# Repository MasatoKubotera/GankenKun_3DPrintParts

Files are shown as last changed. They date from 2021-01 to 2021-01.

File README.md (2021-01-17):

# GankenKun_3DPrintParts

---
## Machine
- ### [ANYCUBIC MEGA-S](https://www.amazon.co.jp/ANYCUBIC-3D%E3%83%97%E3%83%AA%E3%83%B3%E3%82%BF%E3%83%BC-%E6%97%A5%E6%9C%AC%E8%AA%9E%E5%8F%96%E6%89%B1%E8%AA%AC%E6%98%8E%E6%9B%B8%E4%BB%98%E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)

  

  - #### Introduction date
    - 2020/11/19
---
## Software
- ### Create 3D model
  - #### [AUTODESK INVENTOR](https://www.autodesk.co.jp/products/inventor)

- ### 3D Printing
  - #### [Ultimaker Cura](https://ultimaker.com/ja/software/ultimaker-cura)

- ### STL data editing
  - #### [blender](https://www.blender.org/)
  
---
## Folder / File
- ### [PLA](/PLA)
  - #### [README](/PLA/README.md)

- ### [TPU](/TPU)
  - #### [README](/TPU/README.md)

- ### [Temp_Calibration_Tower](/Temp_Calibration_Tower)
  - #### [README](/Temp_Calibration_Tower/README.md)

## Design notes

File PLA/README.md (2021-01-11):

# PLA
---
## Table of contents
-   [Filament](https://github.com/MasatoKubotera/GankenKun_3DPrintParts/tree/master/PLA#filament)
-   [Basic Parameteres](https://github.com/MasatoKubotera/GankenKun_3DPrintParts/tree/master/PLA#basic-parameteres)
-   Parts
    -   [Antenna](https://github.com/MasatoKubotera/GankenKun_3DPrintParts/tree/master/PLA#antenna)
    -   [New_Accelite_Controller_Cover](https://github.com/MasatoKubotera/GankenKun_3DPrintParts/tree/master/PLA#new_accelite_controller_cover)
    -   [SwitchCov](https://github.com/MasatoKubotera/GankenKun_3DPrintParts/tree/master/PLA#switchcov)
    -   [カメラ_外装](https://github.com/MasatoKubotera/GankenKun_3DPrintParts/tree/master/PLA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)
    -   [コックピット](https://github.com/MasatoKubotera/GankenKun_3DPrintParts/tree/master/PLA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)
    -   [腕先](https://github.com/MasatoKubotera/GankenKun_3DPrintParts/tree/master/PLA#%E8%85%95%E5%85%88)

---
## Filament
-   [ANYCUBIC PLA](https://www.amazon.co.jp/ANYCUBIC-3D%E3%83%97%E3%83%AA%E3%83%B3%E3%82%BF%E3%83%BC%E7%94%A8-%E3%83%95%E3%82%A3%E3%83%A9%E3%83%A1%E3%83%B3%E3%83%88-%E7%92%B0%E5%A2%83%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)

    

---
## Basic Parameteres

|Name|Parameter|
|---|---|
|**Infill Density [%]**<br>インフィル密度|20|
|**Infill Pattern**<br>初期レイヤー高さ|Gyroid|
|**Printing Temperature [℃]**<br>印刷温度|200|
|**Bulid Plate Temperature [℃]**<br>ビルドプレート温度|60|
|**Print Speed [mm/s]**<br>印刷速度|60|
|**Initial Layer Speed [mm/s]**<br>初期レイヤー印刷速度|5|
|**Enable Retraction**<br>引き戻し有効|available|
|**Enable Print Cooling**<br>印刷中の冷却を有効にする|available|
|**Build Plate Adhesion Type**<br>ビルドプレート接着タイプ|Skirt|

---
## Antenna

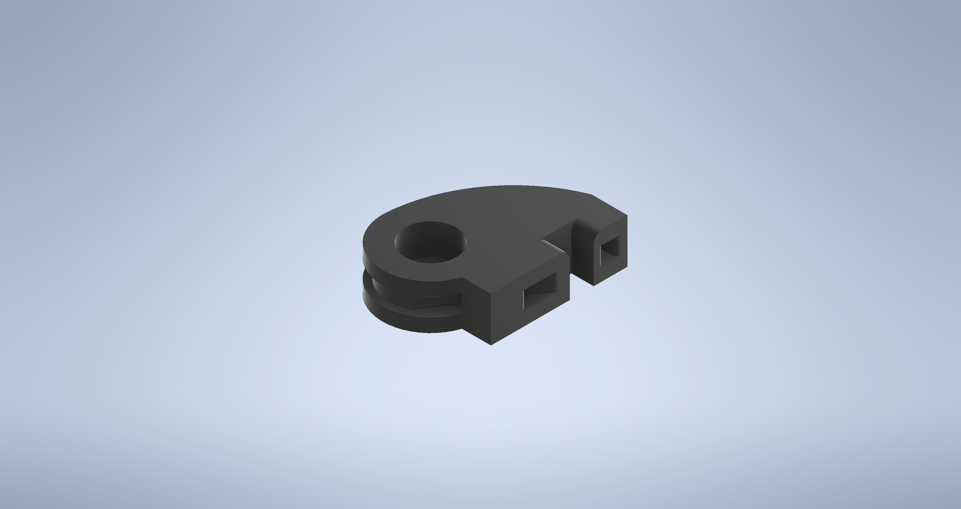
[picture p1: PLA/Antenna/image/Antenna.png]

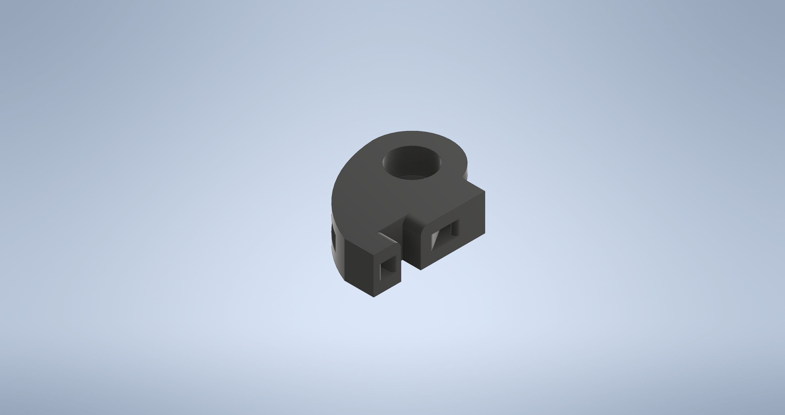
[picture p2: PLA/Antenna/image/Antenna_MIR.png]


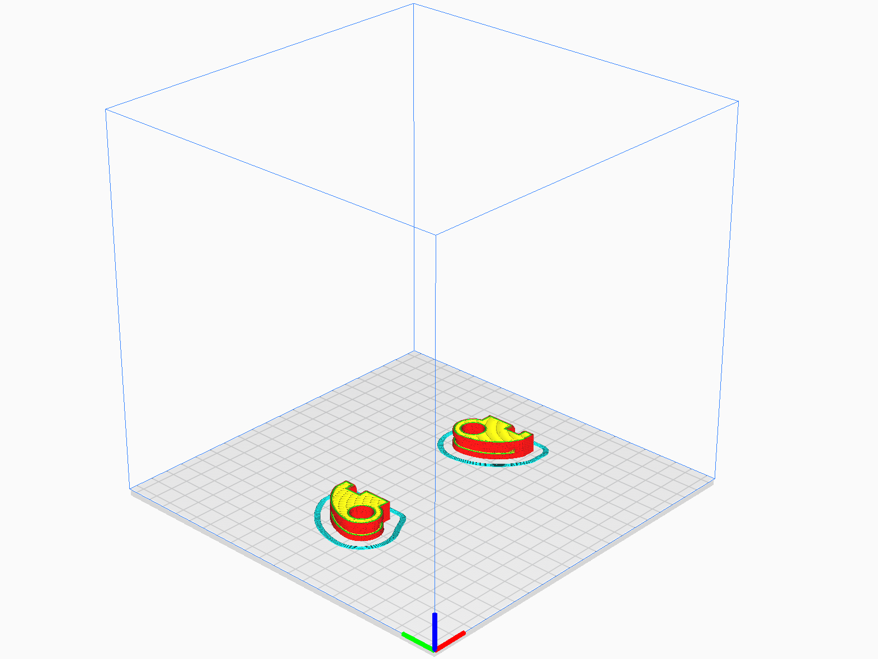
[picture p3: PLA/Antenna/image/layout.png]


-   ### Files

    -   #### CAD  
        -   [Antenna.ipt](https://github.com/citbrains/OpenPlatform/blob/a4b5907f3c764cb437537e5cbbeef6c4c5cdda09/mechanism/OpenPlatform_ver3_0/%E4%B8%8A%E5%8D%8A%E8%BA%AB/%E3%82%B3%E3%83%83%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)

            `OpenPlatform/mechanism/OpenPlatform_ver3_0/上半身/コックピット/コックピット_2/Antenna.ipt`
            
        -   [Antenna_MIR.ipt](https://github.com/citbrains/OpenPlatform/blob/a4b5907f3c764cb437537e5cbbeef6c4c5cdda09/mechanism/OpenPlatform_ver3_0/%E4%B8%8A%E5%8D%8A%E8%BA%AB/%E3%82%B3%E3%83%83%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)

            `OpenPlatform/mechanism/OpenPlatform_ver3_0/上半身/コックピット/コックピット_2/Antenna_MIR.ipt`

    -   #### STL
        -   [Antenna.stl](Antenna.stl)
        -   [Antenna_MIR.stl](Antenna_MIR.stl)

    -   #### Gcode
        -   [Antennas.gcode](Antennas.gcode)

    -   #### Profile
        -   [Antenna.curaprofile](Antenna.curaprofile)

-   ### Characteristical parameteres
    |Parameter Name|Parameter|
    |---|---|
    |**Layer Hight [mm]**<br>レイヤー高さ|0.2|
    |**Generate Support**<br>サポート開始|N/A|

-   ### Quantity
    -   1 pc of each

-   ### Estimated print time
    -   1 h 11 m

-   ### Additional processing
    -   N/A

-   ### Works cited
    -   N/A

---
## New_Accelite_Controller_Cover

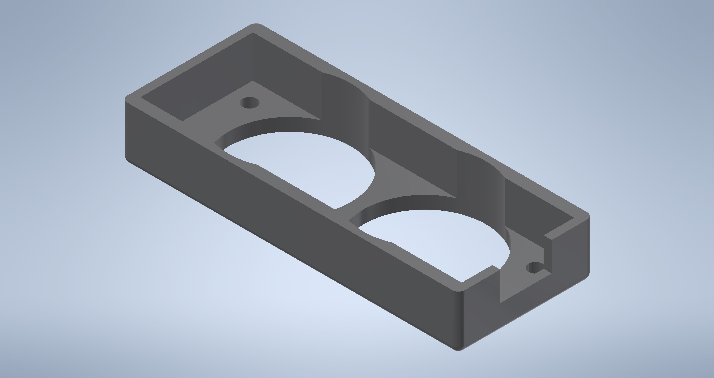
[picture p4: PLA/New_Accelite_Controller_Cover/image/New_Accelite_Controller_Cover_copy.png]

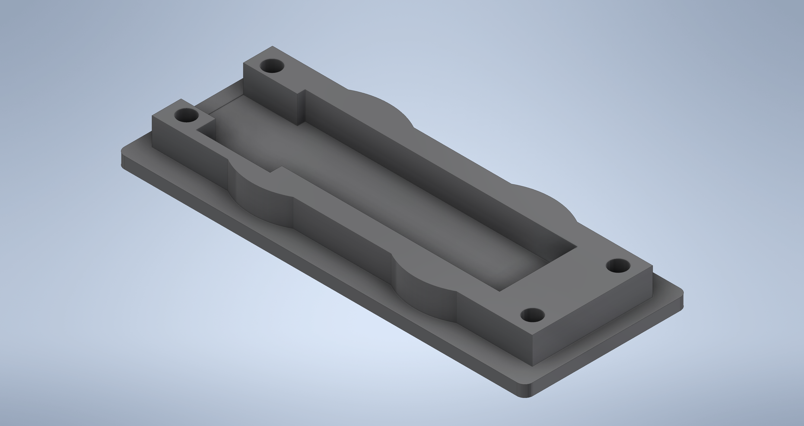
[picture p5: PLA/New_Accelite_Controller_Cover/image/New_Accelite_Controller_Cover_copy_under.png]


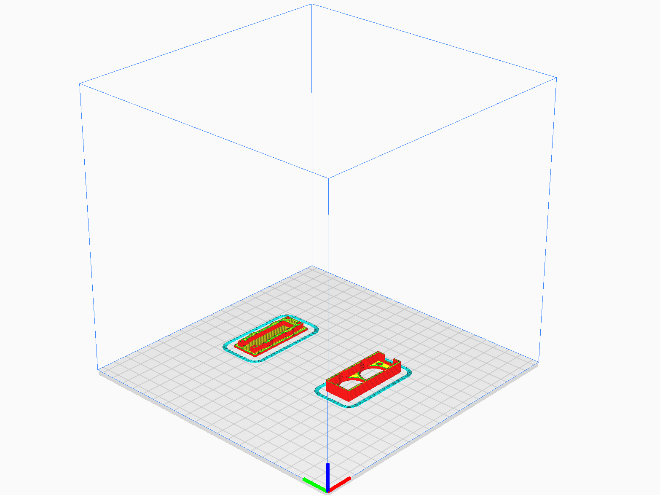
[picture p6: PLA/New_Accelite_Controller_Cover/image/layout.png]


-   ### Files

    -   #### CAD  
        -   [New_Accelite_Controller_Cover_copy.ipt](https://github.com/citbrains/OpenPlatform/blob/a4b5907f3c764cb437537e5cbbeef6c4c5cdda09/mechanism/OpenPlatform_ver3_0/%E4%B8%8A%E5%8D%8A%E8%BA%AB/%E3%82%B3%E3%83%83%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)

            `OpenPlatform/mechanism/OpenPlatform_ver3_0/上半身/コックピット/コックピット_2/New_Accelite_Controller_Cover_copy.ipt`

        - [New_Accelite_Controller_Cover_copy_under.ipt](https://github.com/citbrains/OpenPlatform/blob/a4b5907f3c764cb437537e5cbbeef6c4c5cdda09/mechanism/OpenPlatform_ver3_0/%E4%B8%8A%E5%8D%8A%E8%BA%AB/%E3%82%B3%E3%83%83%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)

            `OpenPlatform/mechanism/OpenPlatform_ver3_0/上半身/コックピット/コックピット_2/New_Accelite_Controller_Cover_copy_under.ipt`

    -   #### STL
        - [New_Accelite_Controller_Cover_copy.stl](New_Accelite_Controller_Cover/New_Accelite_Controller_Cover_copy.stl)

        - [New_Accelite_Controller_Cover_copy_under.stl](New_Accelite_Controller_Cover/New_Accelite_Controller_Cover_copy_under.stl)

    -   #### Gcode
        - [Controller_Cover.gcode](New_Accelite_Controller_Cover/Controller_Cover.gcode)

    -   #### Profile
        - [Controller_Cover.curaprofile](New_Accelite_Controller_Cover/Controller_Cover.curaprofile)

-   ### Characteristical parameteres
    |Parameter Name|Parameter|
    |---|---|
    |**Layer Hight [mm]**<br>レイヤー高さ|0.2|
    |**Generate Support**<br>サポート開始|N/A|

-   ### Quantity
    -   1 pc of each

-   ### Estimated print time
    -   48 m

-   ### Additional processing
    -   N/A

-   ### Works cited
    -   N/A
    
---
## SwitchCov

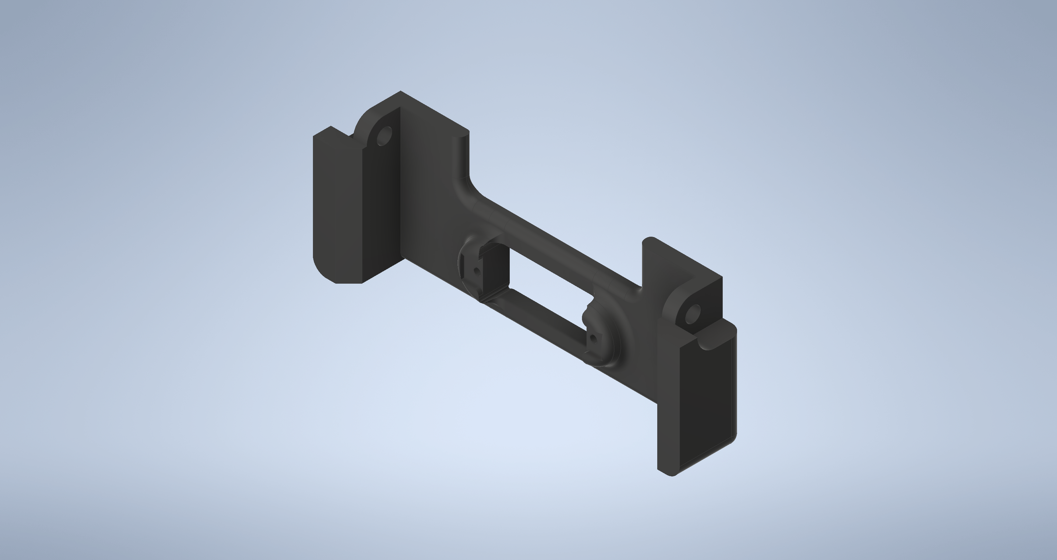
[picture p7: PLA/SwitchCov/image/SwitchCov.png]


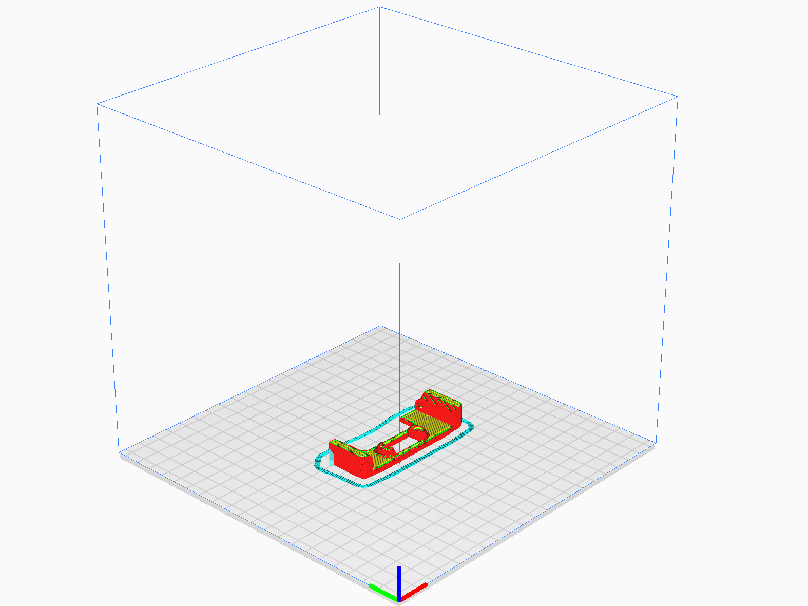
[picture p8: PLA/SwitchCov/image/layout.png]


-   ### Files

    -   #### CAD
        
        Improvement version Branch : [Fix_SwitchCov](https://github.com/citbrains/OpenPlatform/tree/Fix_SwitchCov)

        STL version : commit [1c000b001d7586965ef5ba650b1c151932267094](https://github.com/citbrains/OpenPlatform/tree/1c000b001d7586965ef5ba650b1c151932267094)        

        - [SwitchCov.ipt]()

          `OpenPlatform/mechanism/OpenPlatform_ver3_0/上半身/コックピット/コックピット_2/SwitchCov.ipt`

    -   #### STL
        - [SwitchCov.stl](SwitchCov.stl)

    -   #### Gcode
        - [SwitchCov.gcode](SwitchCov.gcode)

    -   #### Profile
        - [SwitchCov.curaprofile](SwitchCov.curaprofile)

-   ### Characteristical parameteres
    |Parameter Name|Parameter|
    |---|---|
    |**Layer Hight [mm]**<br>レイヤー高さ|0.2|
    |**Generate Support**<br>サポート開始|available|

-   ### Quantity
    -   1 pc

-   ### Estimated print time
    -   1 h 3 m

-   ### Additional processing
    -   ネジ切り M2 * 2

-   ### Works cited
    -   N/A
    
---
## カメラ_外装

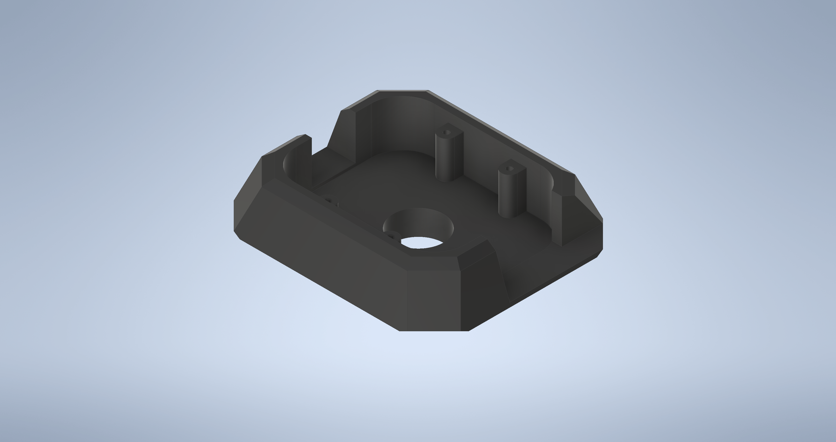
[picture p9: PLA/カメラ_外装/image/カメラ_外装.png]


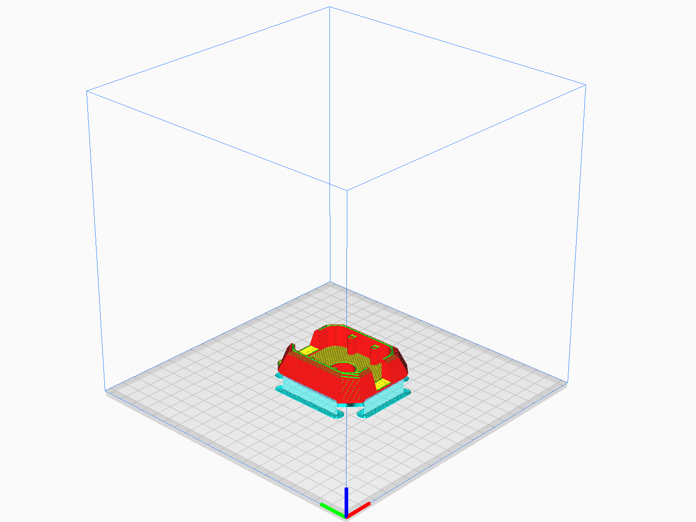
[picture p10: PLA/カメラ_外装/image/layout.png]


-   ### Files

    -   #### CAD

        - [カメラ_外装.ipt](https://github.com/citbrains/OpenPlatform/blob/a4b5907f3c764cb437537e5cbbeef6c4c5cdda09/mechanism/OpenPlatform_ver3_0/%E4%B8%8A%E5%8D%8A%E8%BA%AB/%E9%A0%AD/%E3%82%AB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)

          `OpenPlatform/mechanism/OpenPlatform_ver3_0/上半身/頭/カメラ_外装.ipt
`

    -   #### STL
        - [カメラ_外装.stl](カメラ_外装/カメラ_外装.stl)

    -   #### Gcode
        - [Camera.gcode](カメラ_外装/Camera.gcode)

    -   #### Profile
        - [Camera.curaprofile](カメラ_外装/Camera.curaprofile)

-   ### Characteristical parameteres
    |Parameter Name|Parameter|
    |---|---|
    |**Layer Hight [mm]**<br>レイヤー高さ|0.2|
    |**Generate Support**<br>サポート開始|available|

-   ### Quantity
    -   1 pc

-   ### Estimated print time
    -   2 h 52 m

-   ### Additional processing
    -   ネジ切り M2 * 4

-   ### Works cited
    -   N/A
    
---
## コックピット

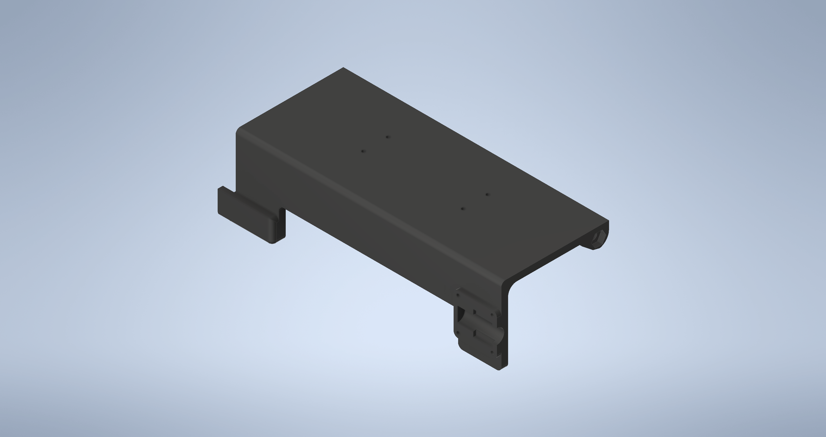
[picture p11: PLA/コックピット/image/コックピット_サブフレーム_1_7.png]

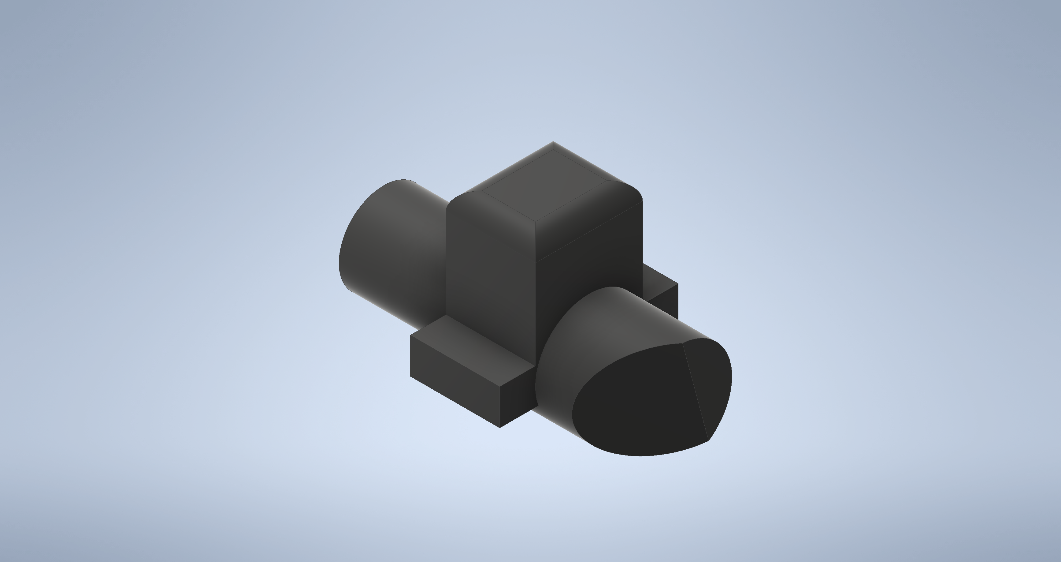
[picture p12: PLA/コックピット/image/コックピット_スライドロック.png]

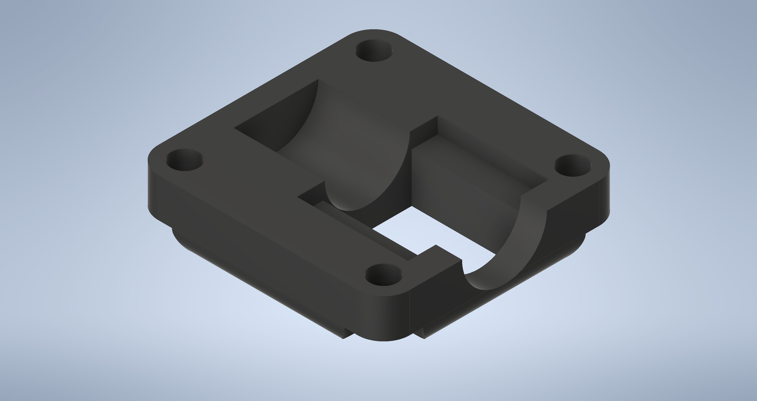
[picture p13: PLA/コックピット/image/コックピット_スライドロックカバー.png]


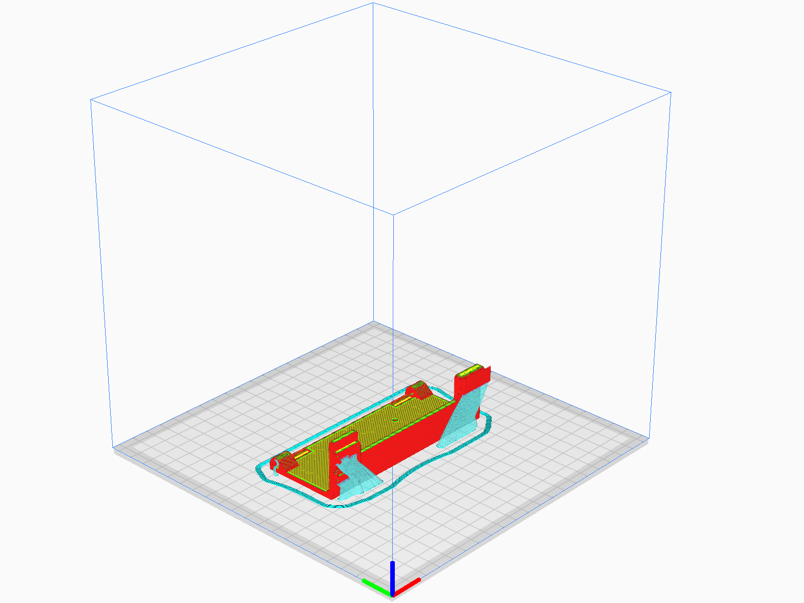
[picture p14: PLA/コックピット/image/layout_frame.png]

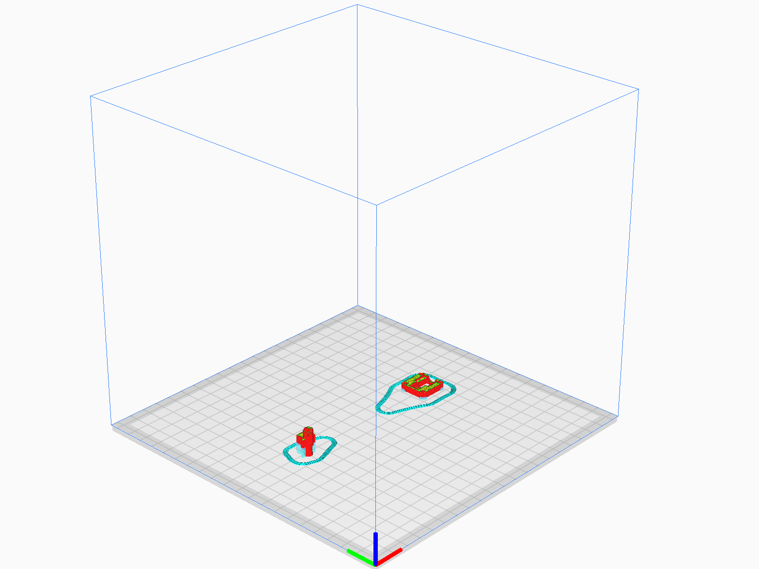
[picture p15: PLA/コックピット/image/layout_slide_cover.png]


-   ### Files

    -   #### CAD

        Improvement version Branch : [New_BatteryBox](https://github.com/citbrains/OpenPlatform/tree/New_BatteryBox)

        STL version : commit [43e9e1346e4216fdac78b60479cbb7ee6bb19e6d](https://github.com/citbrains/OpenPlatform/commit/43e9e1346e4216fdac78b60479cbb7ee6bb19e6d)
        
        - [コックピット_サブフレーム_1_7.ipt](https://github.com/citbrains/OpenPlatform/blob/43e9e1346e4216fdac78b60479cbb7ee6bb19e6d/mechanism/OpenPlatform_ver3_0/%E4%B8%8A%E5%8D%8A%E8%BA%AB/%E3%82%B3%E3%83%83%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)

          `OpenPlatform/mechanism/OpenPlatform_ver3_0/上半身/コックピット/コックピット_2/コックピット_サブフレーム_1_7.ipt`

        - [コックピット_スライドロック.ipt](https://github.com/citbrains/OpenPlatform/blob/43e9e1346e4216fdac78b60479cbb7ee6bb19e6d/mechanism/OpenPlatform_ver3_0/%E4%B8%8A%E5%8D%8A%E8%BA%AB/%E3%82%B3%E3%83%83%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)

          `OpenPlatform/mechanism/OpenPlatform_ver3_0/上半身/コックピット/コックピット_2/コックピット_スライドロック.ipt`

        - [コックピット_スライドロックカバー.ipt](https://github.com/citbrains/OpenPlatform/blob/43e9e1346e4216fdac78b60479cbb7ee6bb19e6d/mechanism/OpenPlatform_ver3_0/%E4%B8%8A%E5%8D%8A%E8%BA%AB/%E3%82%B3%E3%83%83%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)

          `OpenPlatform/mechanism/OpenPlatform_ver3_0/上半身/コックピット/コックピット_2/コックピット_スライドロックカバー.ipt`

    -   #### STL
        - [コックピット_サブフレーム_1_7.stl](コックピット/コックピット_サブフレーム_1_7.stl)

        - [コックピット_スライドロック.stl](コックピット/コックピット_スライドロック.stl)

        - [コックピット_スライドロックカバー.stl](コックピット/コックピット_スライドロックカバー.stl)

    -   #### Gcode
        - [Frame.gcode](コックピット/Frame.gcode)

        - [Slide_Cover.gcode](コックピット/Slide_Cover.gcode)

    -   #### Profile

        - [Frame.curaprofile](コックピット/Frame.curaprofile)

        - [Slide_Cover.curaprofile](コックピット/Slide_Cover.curaprofile)

-   ### Characteristical parameteres
    |Parameter Name|Parameter|
    |---|---|
    |**Layer Hight [mm]**<br>レイヤー高さ|0.2|
    |**Generate Support**<br>サポート開始|available|

    - Support Structure (サポート構造)
      - コックピット_サブフレーム_1_7 : Tree
      - コックピット_スライドロック & コックピット_スライドロックカバー : Normal

-   ### Quantity
    -   1 pc of each

-   ### Estimated print time
    -   コックピット_サブフレーム_1_7
        -   3 h 33 m

    -   コックピット_スライドロック & コックピット_スライドロックカバー
        -   34 m

-   ### Additional processing
    -   コックピット_サブフレーム_1_7
        -   ネジ切り M2 * 4

-   ### Works cited
    -   N/A
    
---
## 腕先

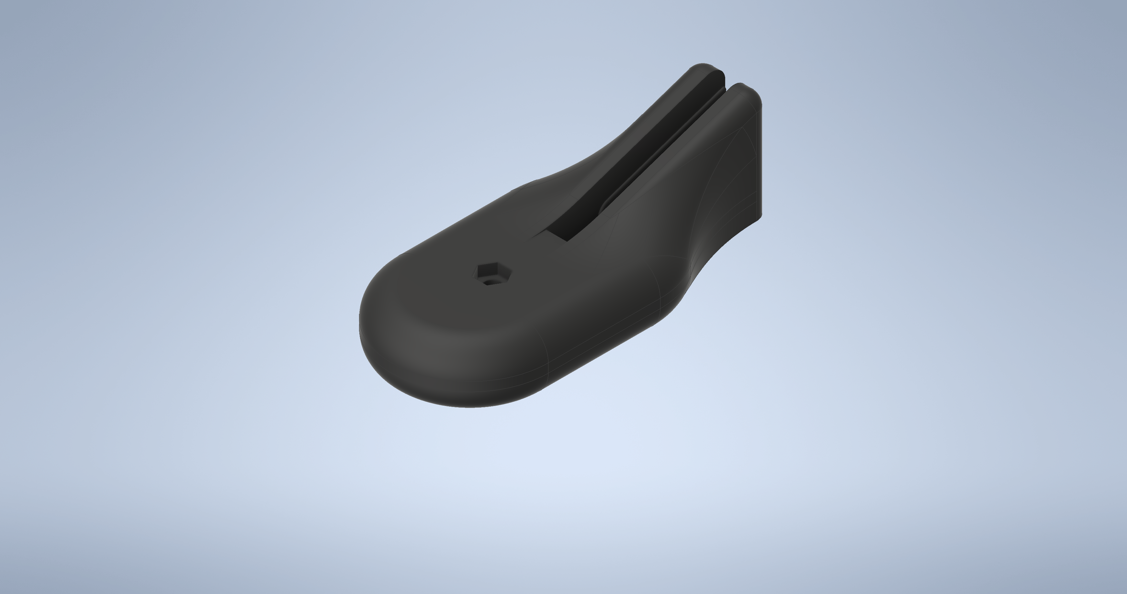
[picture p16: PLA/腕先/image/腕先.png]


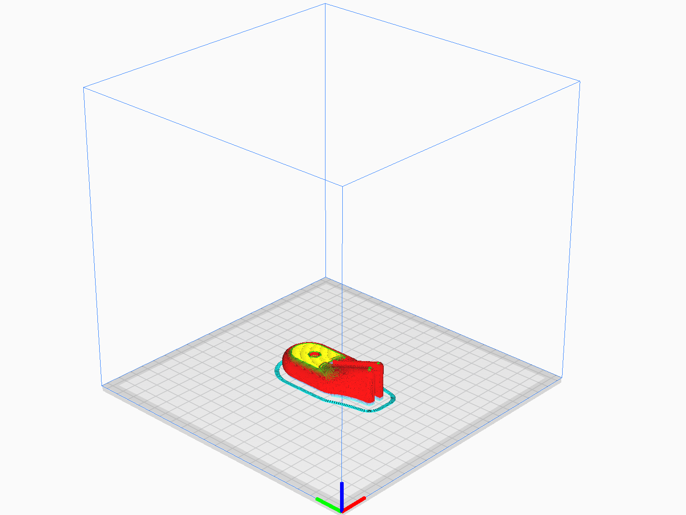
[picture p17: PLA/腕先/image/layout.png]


-   ### Files

    -   #### CAD  
        - [腕先.ipt](https://github.com/citbrains/OpenPlatform/blob/a4b5907f3c764cb437537e5cbbeef6c4c5cdda09/mechanism/OpenPlatform_ver3_0/%E4%B8%8A%E5%8D%8A%E8%BA%AB/%E8%85%95/%E8%85%95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)

          `OpenPlatform/mechanism/OpenPlatform_ver3_0/上半身/腕/腕先.ipt`

    -   #### STL
        - [腕先.stl](腕先/腕先.stl)

    -   #### Gcode
        - [Hand.gcode](腕先/Hand.gcode)

    -   #### Profile
        - [Hand.curaprofile](腕先/Hand.curaprofile)

-   ### Characteristical parameteres
    |Parameter Name|Parameter|
    |---|---|
    |**Layer Hight [mm]**<br>レイヤー高さ|0.2|
    |**Generate Support**<br>サポート開始|available|

-   ### Quantity
    -   2 pcs

-   ### Estimated print time
    -   1 h 36 m / 1 pc

-   ### Additional processing
    -   N/A

-   ### Works cited
    -   N/A

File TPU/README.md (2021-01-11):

# TPU
---
## Table of contents
-   [Filament](https://github.com/MasatoKubotera/GankenKun_3DPrintParts/tree/master/TPU#filament)
-   [Basic Parameteres](https://github.com/MasatoKubotera/GankenKun_3DPrintParts/tree/master/TPU#basic-parameteres)
-   Parts
    -   [CameraCable_Assist](https://github.com/MasatoKubotera/GankenKun_3DPrintParts/tree/master/TPU#cameracable_assist)
    -   [FreundBumper_Stand](https://github.com/MasatoKubotera/GankenKun_3DPrintParts/tree/master/TPU#freundbumper_stand)
    -   [FrontBumper_main](https://github.com/MasatoKubotera/GankenKun_3DPrintParts/tree/master/TPU#frontbumper_main)
    -   [RearBumper_Lower](https://github.com/MasatoKubotera/GankenKun_3DPrintParts/tree/master/TPU#rearbumper_lower)
    -   [SideBumper](https://github.com/MasatoKubotera/GankenKun_3DPrintParts/tree/master/TPU#sidebumper)

---
## Filament
-   [Pxmalion Flexible TPU](https://www.amazon.co.jp/dp/B074W3Y44S)

    

---
## Basic Parameteres

|Name|Parameter|
|---|---|
|**Initial Layer Hight [mm]**<br>初期レイヤー高さ|0.3|
|**Initial Layer Line Width [%]**<br>|125|
|**Printing Temperature [℃]**<br>印刷温度|190|
|**Bulid Plate Temperature [℃]**<br>ビルドプレート温度|0 ~ 60|
|**Print Speed [mm/s]**<br>印刷速度|30|
|**Initial Layer Speed [mm/s]**<br>初期レイヤー印刷速度|15|
|**Enable Retraction**<br>引き戻し有効|N/A|
|**Enable Print Cooling**<br>印刷中の冷却を有効にする|available|
|**Generate Support**<br>サポート開始|N/A|

---
## CameraCable_Assist

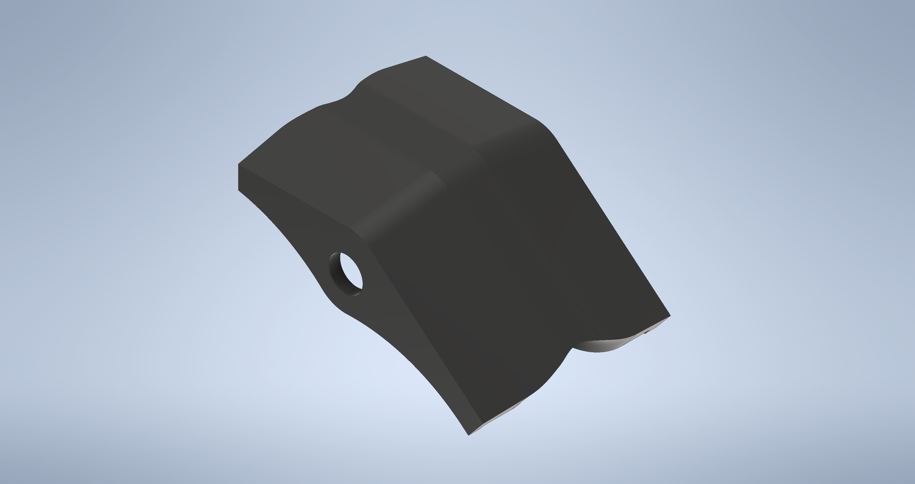
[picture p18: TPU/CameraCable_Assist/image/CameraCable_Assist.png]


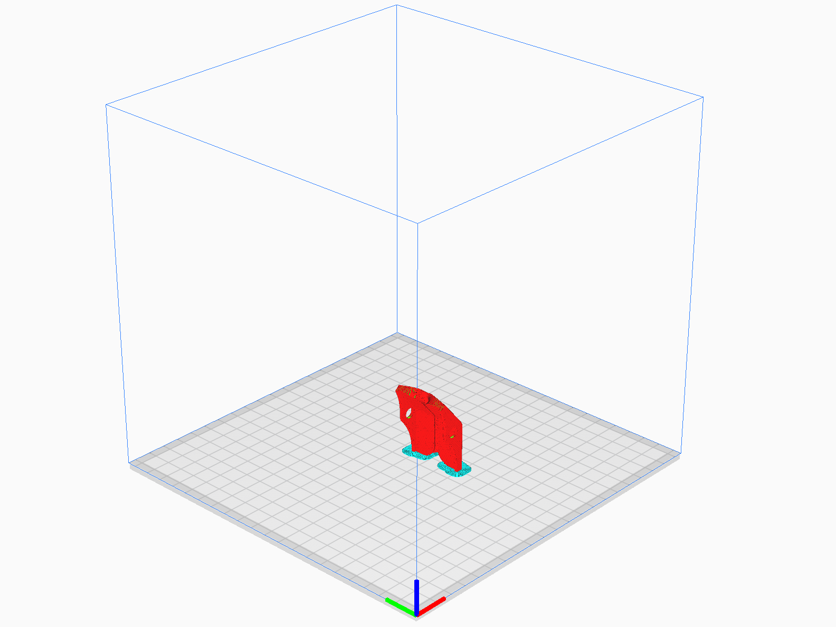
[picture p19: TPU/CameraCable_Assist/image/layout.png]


-   ### Files

    -   #### CAD  
        -   [CameraCable_Assist.ipt](https://github.com/citbrains/OpenPlatform/tree/a4b5907f3c764cb437537e5cbbeef6c4c5cdda09/mechanism/OpenPlatform_ver3_0/%E4%B8%8A%E5%8D%8A%E8%BA%AB/%E9%A0%AD/CameraCab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)

            `OpenPlatform/mechanism/OpenPlatform_ver3_0/上半身/頭/CameraCable_Assist.ipt`

    -   #### STL
        -   [CameraCable_Assist.stl](CameraCable_Assist/CameraCable_Assist.stl)

    -   #### Gcode
        -   [Cable_Assist.gcode](CameraCable_Assist/Cable_Assist.gcode)

    -   #### Profile
        -   [Cable_Assist.curaprofile](CameraCable_Assist/Cable_Assist.curaprofile)

-   ### Characteristical parameteres
    |Parameter Name|Parameter|
    |---|---|
    |**Infill Density [%]**<br>インフィル密度|100|
    |**Layer Hight [mm]**<br>レイヤー高さ|0.2|
    |**Bulid Plate Temperature [℃]**<br>ビルドプレート温度|0|
    |**Build Plate Adhesion Type**<br>ビルドプレート接着タイプ|Brim|

-   ### Quantity
    -   1 pc

-   ### Estimated print time
    -   1 h 36 m

-   ### Additional processing
    -   N/A

-   ### Works cited
    -   N/A

---
## FreundBumper_Stand

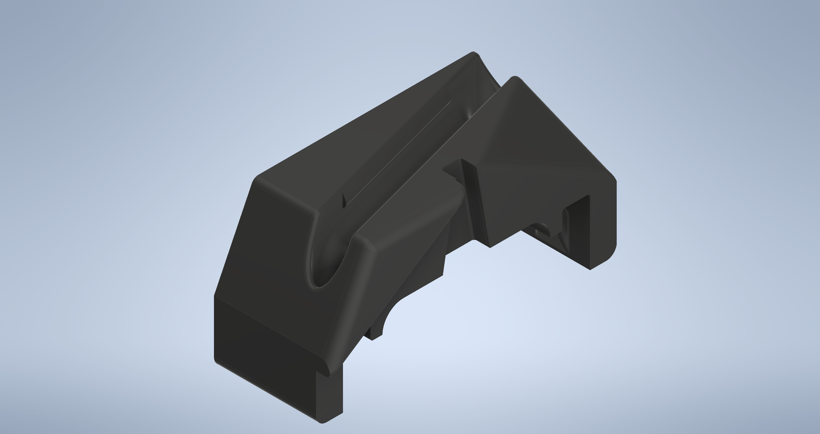
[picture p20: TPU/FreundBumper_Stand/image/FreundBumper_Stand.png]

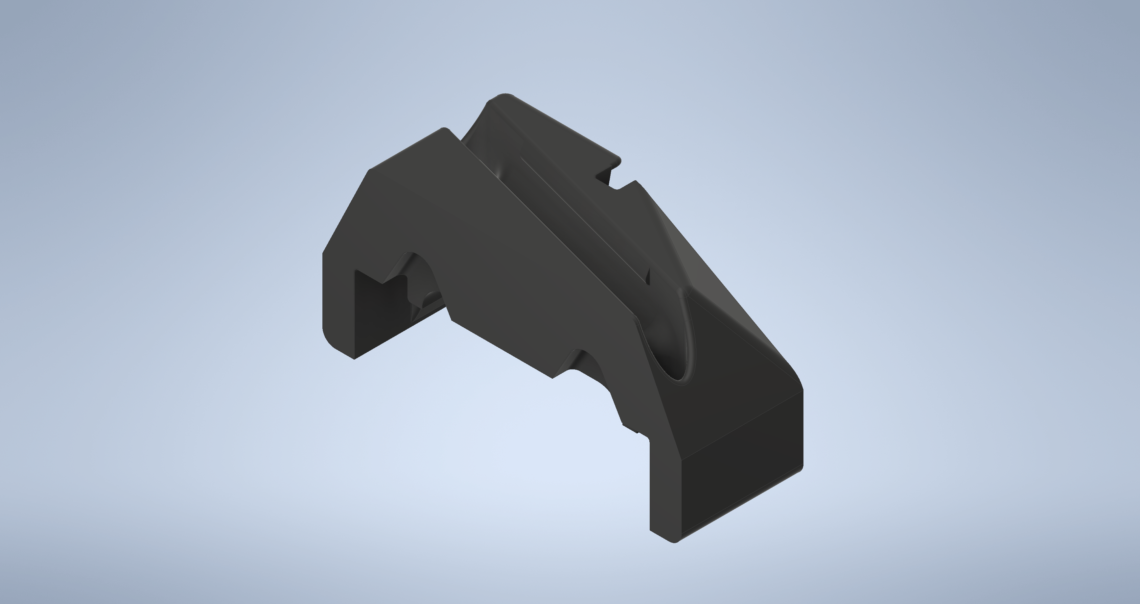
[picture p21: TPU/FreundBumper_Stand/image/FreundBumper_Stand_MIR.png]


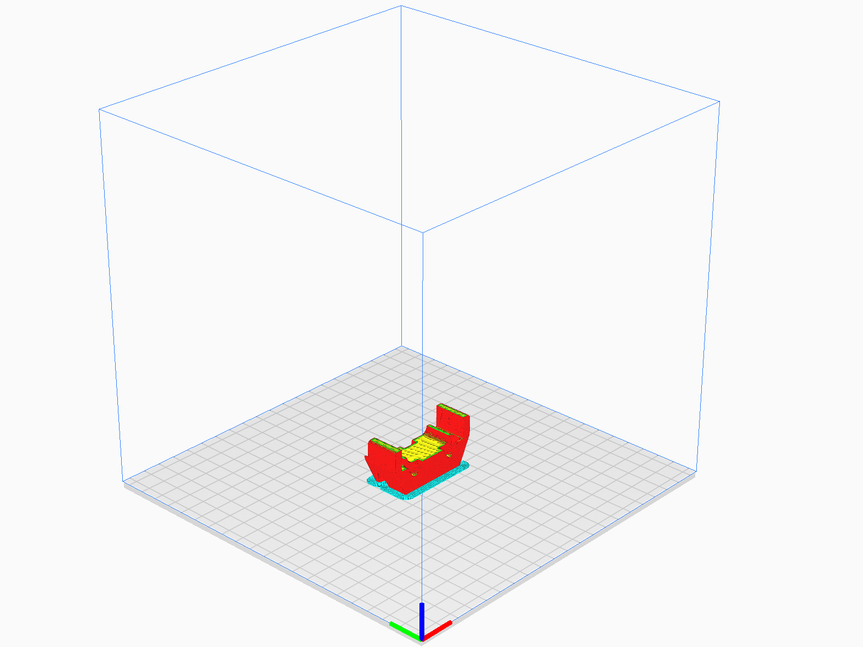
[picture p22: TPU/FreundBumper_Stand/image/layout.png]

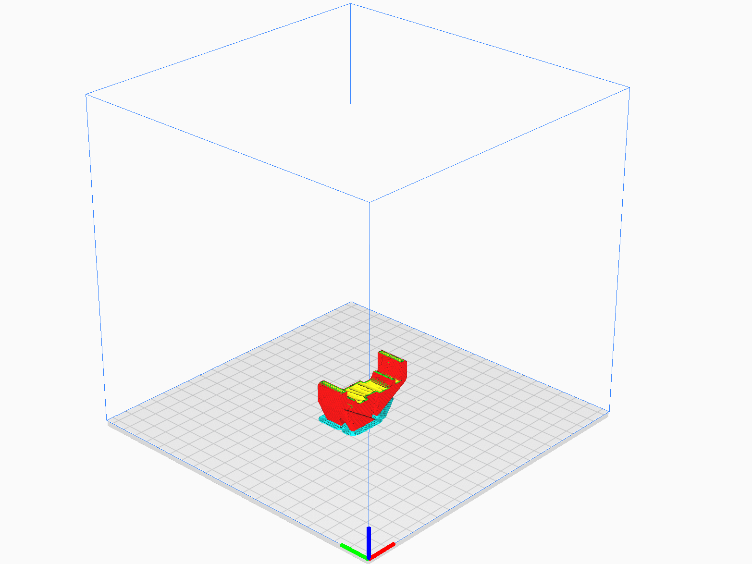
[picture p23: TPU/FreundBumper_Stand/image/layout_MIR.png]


-   ### Files

    -   #### CAD  
        -   [FreundBumper_Stand.ipt](https://github.com/citbrains/OpenPlatform/tree/a4b5907f3c764cb437537e5cbbeef6c4c5cdda09/mechanism/OpenPlatform_ver3_0/%E4%B8%8A%E5%8D%8A%E8%BA%AB/%E8%83%B4%E4%BD%93/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)

            `OpenPlatform/mechanism/OpenPlatform_ver3_0/上半身/胴体/FreundBumper_Stand.ipt`

        -   [FreundBumper_Stand_MIR.ipt](https://github.com/citbrains/OpenPlatform/tree/a4b5907f3c764cb437537e5cbbeef6c4c5cdda09/mechanism/OpenPlatform_ver3_0/%E4%B8%8A%E5%8D%8A%E8%BA%AB/%E8%83%B4%E4%BD%93/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)

            `OpenPlatform/mechanism/OpenPlatform_ver3_0/上半身/胴体/FreundBumper_Stand_MIR.ipt`

    -   #### STL
        -   [FreundBumper_Stand.stl](FreundBumper_Stand/FreundBumper_Stand.stl)
        -   [FreundBumper_Stand_MIR.stl](FreundBumper_Stand/FreundBumper_Stand_MIR.stl)

    -   #### Gcode
        -   [Bumper_Stand.gcode](FreundBumper_Stand/Bumper_Stand.gcode)
        -   [Bumper_Stand_MIR.gcode](FreundBumper_Stand/Bumper_Stand_MIR.gcode)

    -   #### Profile
        -   [Bumper_Stand.curaprofile](FreundBumper_Stand/Bumper_Stand.curaprofile)

-   ### Characteristical parameteres
    |Parameter Name|Parameter|
    |---|---|
    |**Infill Density [%]**<br>インフィル密度|100|
    |**Layer Hight [mm]**<br>レイヤー高さ|0.2|
    |**Bulid Plate Temperature [℃]**<br>ビルドプレート温度|60|
    |**Build Plate Adhesion Type**<br>ビルドプレート接着タイプ|Brim|

-   ### Quantity
    -   1 pc of each

-   ### Estimated print time
    -   3 h 22 m of each

-   ### Additional processing
    -   N/A

-   ### Works cited
    -   [issue](https://github.com/citbrains/citbrains_humanoid/issues/999#issuecomment-499572870)

---
## FrontBumper_main

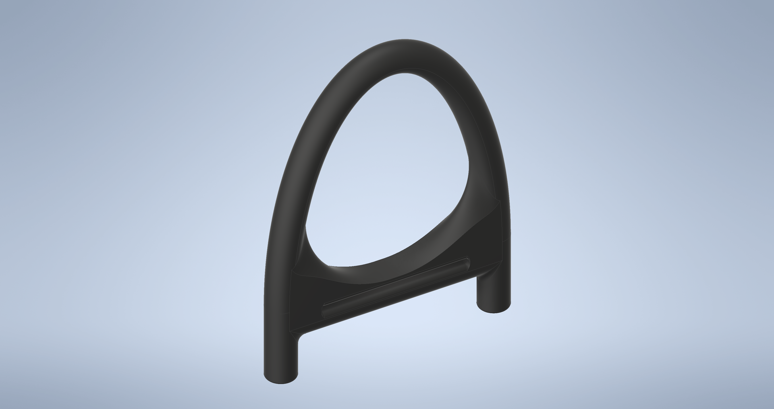
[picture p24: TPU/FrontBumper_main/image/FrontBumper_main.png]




-   ### Files

    -   #### CAD  
        -   [FrontBumper_main.ipt](https://github.com/citbrains/OpenPlatform/blob/a4b5907f3c764cb437537e5cbbeef6c4c5cdda09/mechanism/OpenPlatform_ver3_0/%E4%B8%8A%E5%8D%8A%E8%BA%AB/%E8%83%B4%E4%BD%93/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)

            `OpenPlatform/mechanism/OpenPlatform_ver3_0/上半身/胴体/FrontBumper_main.ipt`

    -   #### STL
        -   [FrontBumpe_mainr.stl](FrontBumpe_mainr/FrontBumpe_mainr.stl)

    -   #### Gcode
        -   [FrontBumper_main.gcode](FrontBumpe_mainr/FrontBumper_main.gcode)

    -   #### Profile
        -   [FrontBumper.curaprofeil](FrontBumpe_mainr/FrontBumper.curaprofeil)

-   ### Characteristical parameteres
    |Parameter Name|Parameter|
    |---|---|
    |**Infill Density [%]**<br>インフィル密度|100|
    |**Layer Hight [mm]**<br>レイヤー高さ|0.1|
    |**Bulid Plate Temperature [℃]**<br>ビルドプレート温度|60|
    |**Build Plate Adhesion Type**<br>ビルドプレート接着タイプ|Skirt|

-   ### Quantity
    -   2 pcs

-   ### Estimated print time
    -   2 h 46 m / 1 pc

-   ### Additional processing
    -   N/A

-   ### Works cited
    -   [issue](https://github.com/citbrains/citbrains_humanoid/issues/999#issuecomment-499572870)

---
## RearBumper_Lower







-   ### Files

    -   #### CAD  
        -   [RearBumper_Lower.ipt](https://github.com/citbrains/OpenPlatform/blob/a4b5907f3c764cb437537e5cbbeef6c4c5cdda09/mechanism/OpenPlatform_ver3_0/%E4%B8%8A%E5%8D%8A%E8%BA%AB/%E8%83%B4%E4%BD%93/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)

            `OpenPlatform/mechanism/OpenPlatform_ver3_0/上半身/胴体/RearBumper_Lower.ipt`

        -   [RearBumper_Lower_MIR.ipt](https://github.com/citbrains/OpenPlatform/blob/a4b5907f3c764cb437537e5cbbeef6c4c5cdda09/mechanism/OpenPlatform_ver3_0/%E4%B8%8A%E5%8D%8A%E8%BA%AB/%E8%83%B4%E4%BD%93/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)
            
            `OpenPlatform/mechanism/OpenPlatform_ver3_0/上半身/胴体/RearBumper_Lower_MIR.ipt`

    -   #### STL
        -   [RearBumper_Lower.stl](RearBumper_Lower/RearBumper_Lower.stl)
        -   [RearBumper_Lower_MIR.stl](RearBumper_Lower/RearBumper_Lower_MIR.stl)

    -   #### Gcode
        -   [Bumper_Lower.gcode](RearBumper_Lower/Bumper_Lower.gcode)
        -   [Bumper_Lower_MIR.gcode](RearBumper_Lower/Bumper_Lower/RearBumper_Lower_MIR.gcode)

    -   #### Profile
        -   [RearBumpere_Lower.curaprofile](RearBumper_Lower/RearBumpere_Lower.curaprofile)

-   ### Characteristical parameteres
    |Parameter Name|Parameter|
    |---|---|
    |**Infill Density [%]**<br>インフィル密度|100|
    |**Layer Hight [mm]**<br>レイヤー高さ|0.2|
    |**Bulid Plate Temperature [℃]**<br>ビルドプレート温度|60|
    |**Build Plate Adhesion Type**<br>ビルドプレート接着タイプ|Skirt|

-   ### Quantity
    -   1 pc of each

-   ### Estimated print time
    -   2 h 51 m of each

-   ### Additional processing
    -   N/A

-   ### Works cited
    -   [issue](https://github.com/citbrains/citbrains_humanoid/issues/1197)

---
## SideBumper





-   ### Files

    -   #### CAD  
        -   [SideBumper.ipt](https://github.com/citbrains/OpenPlatform/blob/a4b5907f3c764cb437537e5cbbeef6c4c5cdda09/mechanism/OpenPlatform_ver3_0/%E4%B8%8A%E5%8D%8A%E8%BA%AB/%E8%85%95/SideBumpe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)

            `OpenPlatform/mechanism/OpenPlatform_ver3_0/上半身/腕/SideBumper.ipt`

    -   #### STL
        -   [SideBumper.stl](SideBumper/SideBumper.stl)

    -   #### Gcode
        -   [SideBumper.gcode](SideBumper/SideBumper.gcode)

    -   #### Profile
        -   [SideBumper.curaprofile](SideBumper/SideBumper.curaprofile)

-   ### Characteristical parameteres
    |Parameter Name|Parameter|
    |---|---|
    |**Infill Density [%]**<br>インフィル密度|15|
    |**Layer Hight [mm]**<br>レイヤー高さ|0.2|
    |**Bulid Plate Temperature [℃]**<br>ビルドプレート温度|60|
    |**Build Plate Adhesion Type**<br>ビルドプレート接着タイプ|Skirt|

-   ### Quantity
    -   2 pcs

-   ### Estimated print time
    -   1 h 57 m / 1 pc

-   ### Additional processing
    -   N/A

-   ### Works cited
    -   [issue](https://github.com/citbrains/citbrains_humanoid/issues/999#issuecomment-499572870)

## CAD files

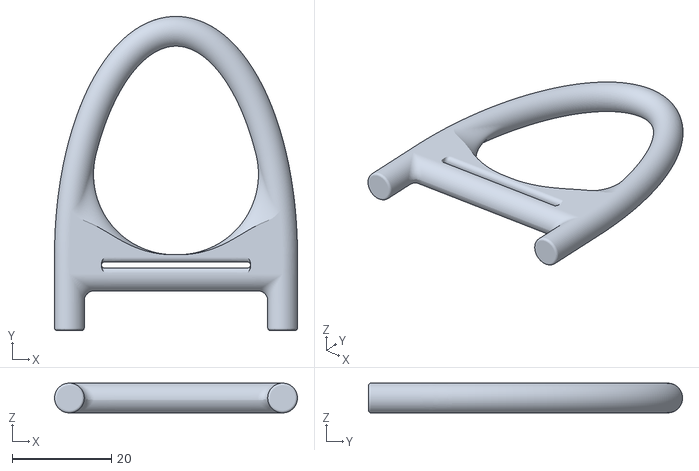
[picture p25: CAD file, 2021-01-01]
TPU/FrontBumper_main/FrontBumper_main.stl
49.0 x 63.3 x 6.00

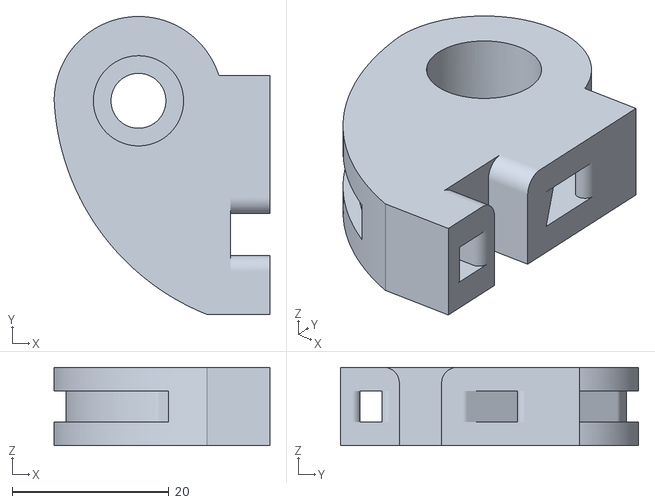
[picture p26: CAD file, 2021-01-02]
PLA/Antenna/Antenna_MIR.stl
27.5 x 38.0 x 10.0

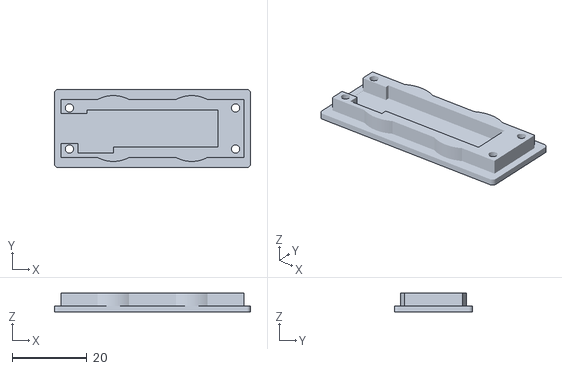
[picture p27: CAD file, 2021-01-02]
PLA/New_Accelite_Controller_Cover/New_Accelite_Controller_Cover_copy_under.stl
52.5 x 21.0 x 5.00

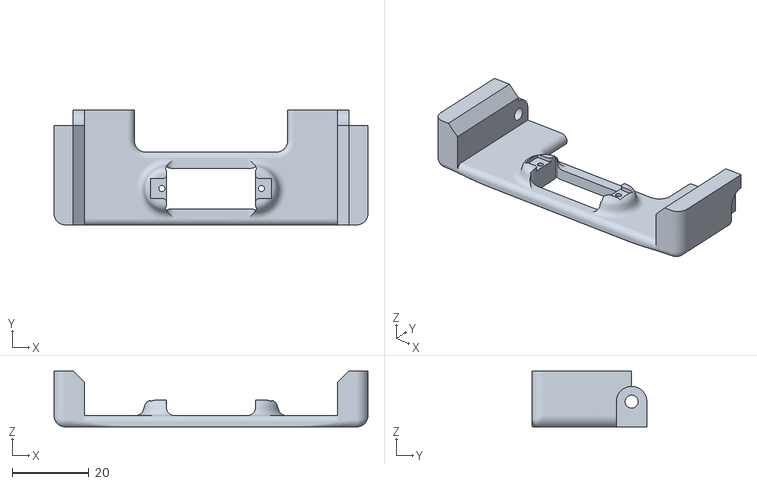
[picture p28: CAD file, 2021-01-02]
PLA/SwitchCov/SwitchCov.stl
82.0 x 30.0 x 14.6

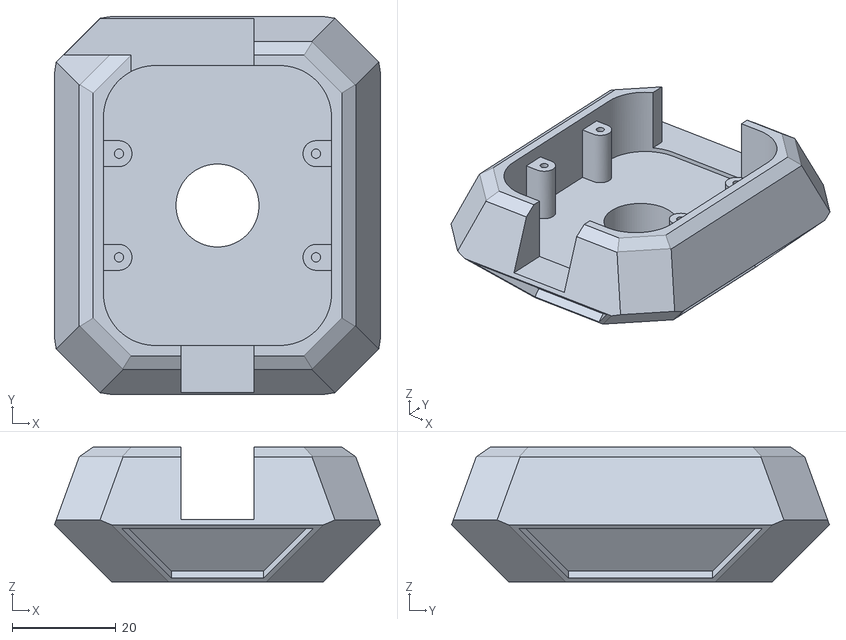
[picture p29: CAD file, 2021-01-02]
PLA/カメラ_外装/カメラ_外装.stl
62.9 x 72.9 x 26.0

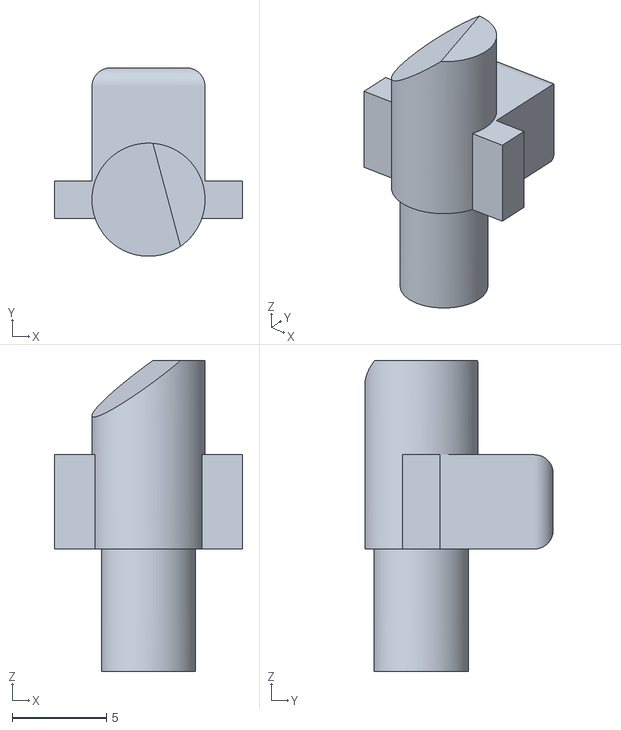
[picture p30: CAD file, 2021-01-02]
PLA/コックピット/コックピット_スライドロック.stl
10.0 x 10.0 x 16.5

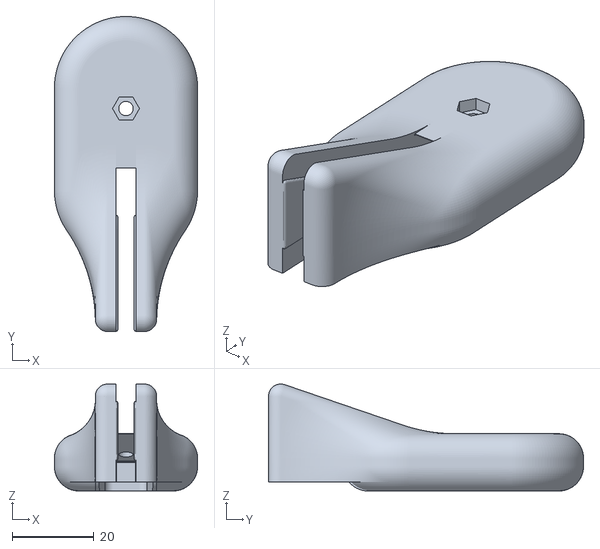
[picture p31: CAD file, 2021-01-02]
PLA/腕先/腕先.stl
35.0 x 77.0 x 26.2

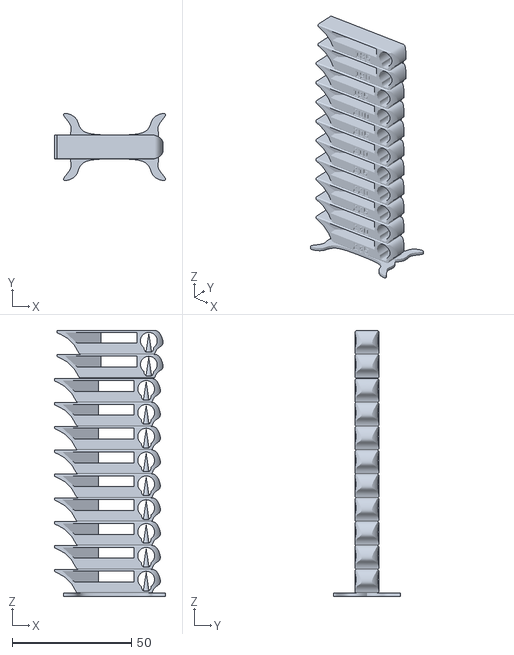
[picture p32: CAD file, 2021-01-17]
Temp_Calibration_Tower/TPU/SmartTemperatureTower_TPU_185-235.stl
46.7 x 28.2 x 111.6

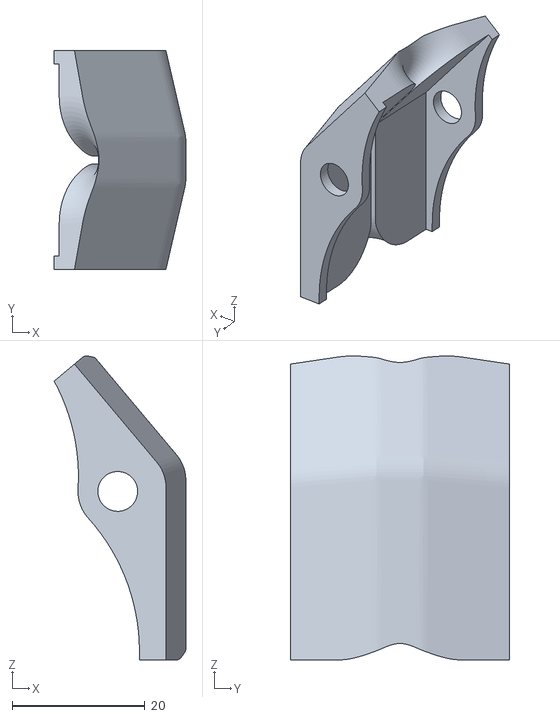
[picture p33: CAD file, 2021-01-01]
TPU/CameraCable_Assist/CameraCable_Assist.stl
19.9 x 33.0 x 45.8

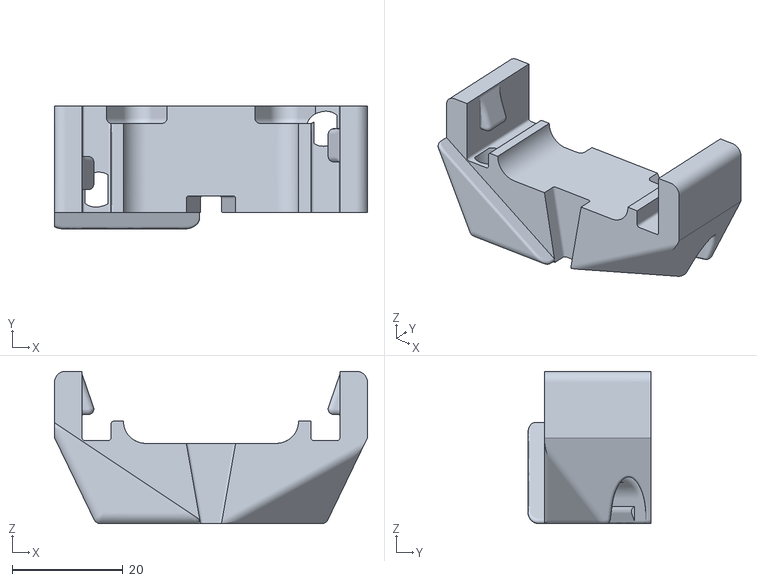
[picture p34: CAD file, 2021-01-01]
TPU/FreundBumper_Stand/FreundBumper_Stand_MIR.stl
56.5 x 22.2 x 27.5

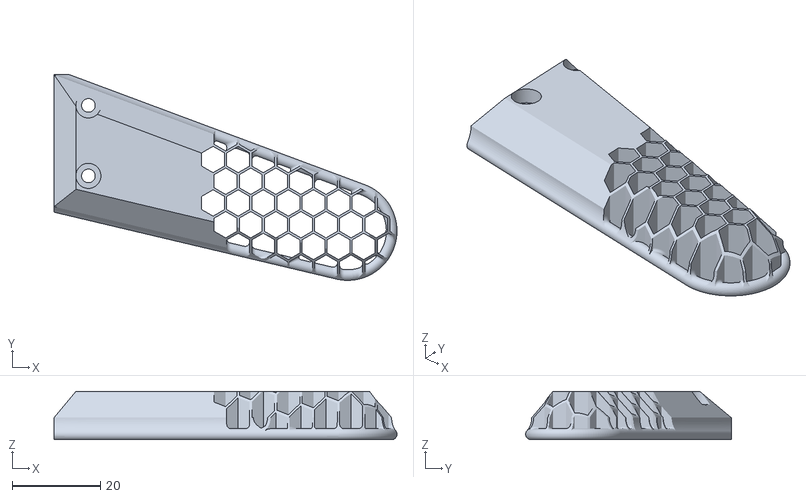
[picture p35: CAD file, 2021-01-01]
TPU/RearBumper_Lower/RearBumper_Lower.stl
77.9 x 46.7 x 11.0

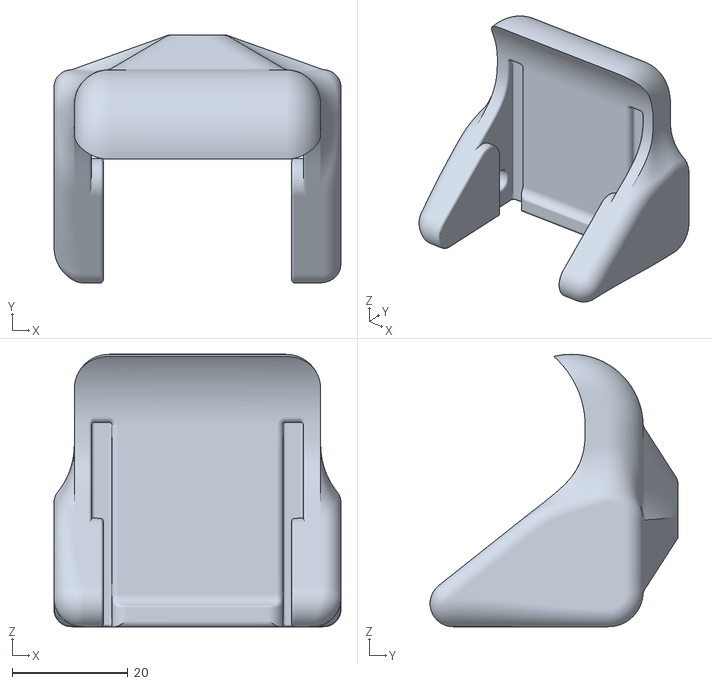
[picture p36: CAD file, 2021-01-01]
TPU/SideBumper/SideBumper.stl
49.5 x 42.7 x 47.0

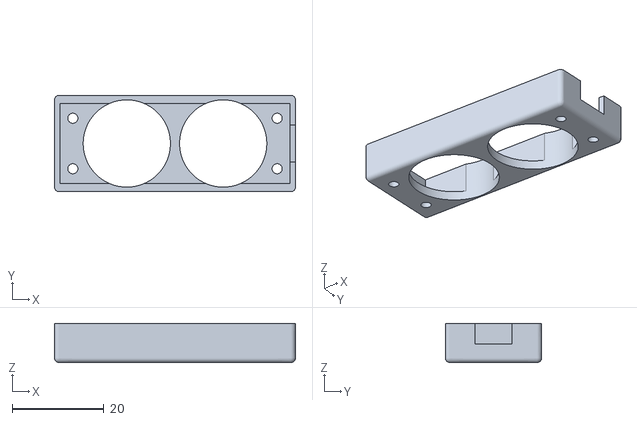
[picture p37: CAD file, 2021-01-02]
PLA/New_Accelite_Controller_Cover/New_Accelite_Controller_Cover_copy.stl
52.5 x 21.0 x 8.50

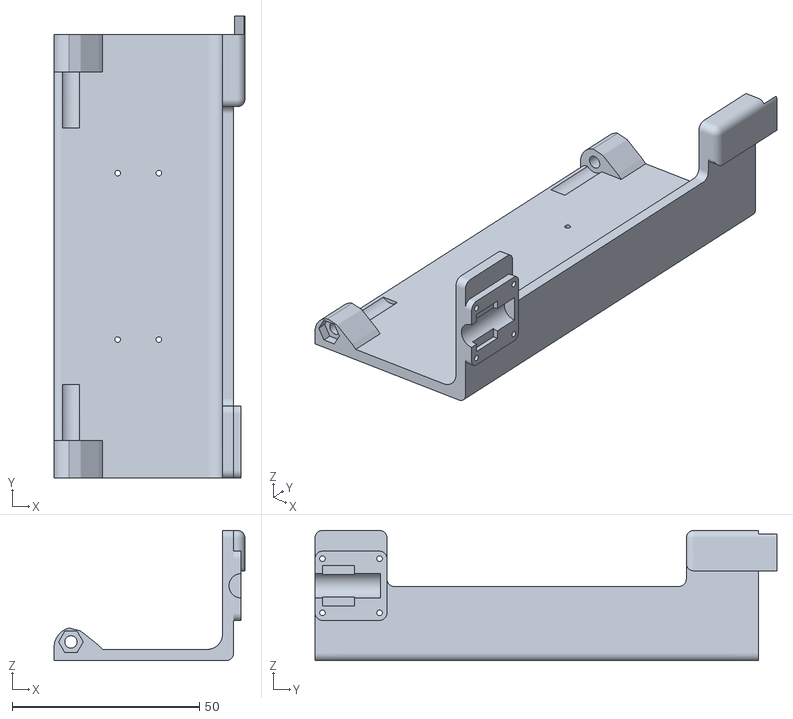
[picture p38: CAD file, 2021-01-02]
PLA/コックピット/コックピット_サブフレーム_1_7.stl
51.0 x 123.5 x 34.8

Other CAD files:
PLA/Antenna/Antenna.stl
TPU/FreundBumper_Stand/FreundBumper_Stand.stl
TPU/RearBumper_Lower/RearBumper_Lower_MIR.stl
PLA/コックピット/コックピット_スライドロックカバー.stl

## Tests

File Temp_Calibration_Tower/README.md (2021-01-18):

# Temp_Calibration_Tower

最適なノズル温度を見つけるために，ノズル温度を5℃ずつ変えたテストパターンを出力する．

---
## Table of contents
- [Temp calibration tower for TPU](https://github.com/MasatoKubotera/GankenKun_3DPrintParts/tree/master/Temp_Calibration_Tower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)
- [How to change the temperature for each layer](https://github.com/MasatoKubotera/GankenKun_3DPrintParts/tree/master/Temp_Calibration_Tower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)
- [LICENSE](https://github.com/MasatoKubotera/GankenKun_3DPrintParts/tree/master/Temp_Calibration_Tower#license)

---
## Temp calibration tower for TPU

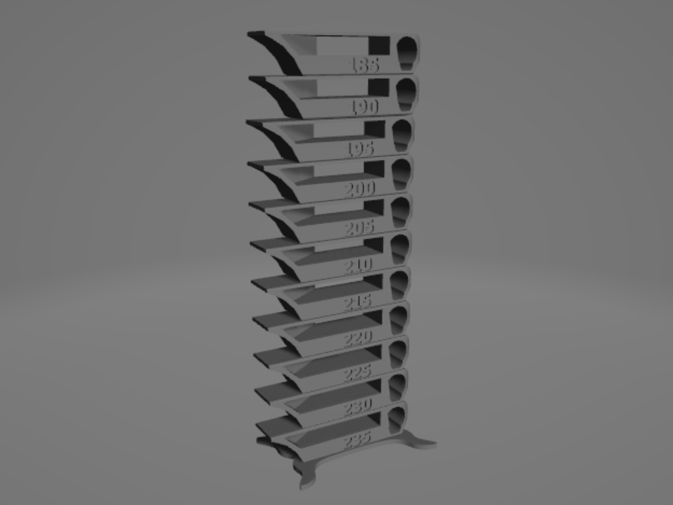
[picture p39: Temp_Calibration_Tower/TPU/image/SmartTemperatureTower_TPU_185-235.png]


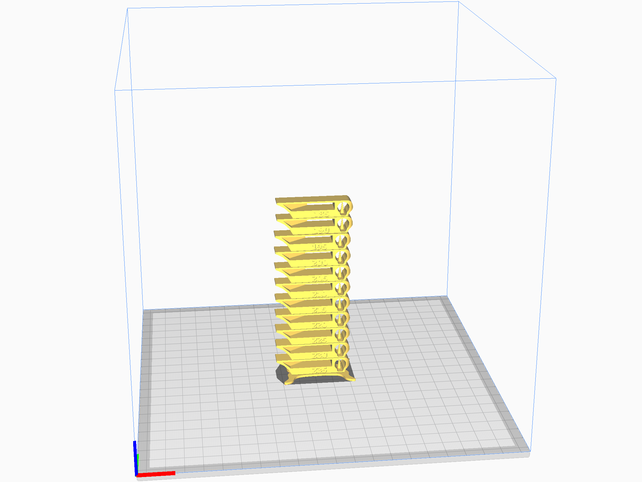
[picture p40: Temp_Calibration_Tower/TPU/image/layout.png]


- ### Temp range
  185~235℃

- ### Files

  - #### STL
    - [SmartTemperatureTower_TPU_185-235.stl](TPU/SmartTemperatureTower_TPU_185-235.stl)

  - #### Gcode
    - [TowerTPU_185-235.gcode](TPU/TowerTPU_185-235.gcode)

  - #### Profile
    - [Temp_Tower_185-235.curaprofile](TPU/Temp_Tower_185-235.curaprofile)

-   ### Estimated print time
    -   4 h 2 m

---
## How to change the temperature for each layer
1.  拡張子→後処理→G-codeを修正を選択．

  

2. スクリプトを加える→ **ChangeAtZ 5.2.1(Experimental)** を選択．

  

3.  **Change Height** に変化させる高さを入力．**Change Extruder 1 Temp** に &#10004; して， **Extruder 1 Temp** に温度を入力する．
  - Height
    - Stand : 1.6 [mm]
    - each Temp Floor : 10 [mm]

  ※ 初期温度は通常の設定で行う．







---
## LICENSE
### [Creative Commons License CC-BY-SA](http://creativecommons.org/licenses/by-sa/3.0/deed.ja)



[SmartTemperatureTower_TPU_185-235](SmartTemperatureTower_TPU_185-235.stl) modified the original [Smart compact temperature calibration tower](http://www.thingiverse.com/thing:2729076).

Smart compact temperature calibration tower (http://www.thingiverse.com/thing:2729076) by gaaZolee is licensed under the Creative Commons - Attribution - Share Alike license.

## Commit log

2021-01-01 TPU files upload
    [CameraCable_Assist.stl, FreundBumper_Stand.stl, FreundBumper_Stand_MIR.stl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]
2021-01-02 PLA files upload
    [Antenna.stl, Antenna_MIR.stl, New_Accelite_Controller_Cover_copy.stl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]
2021-01-16 add Temp calibration tower for TPU
    [SmartTemperatureTower_TPU_185-235.stl]
2021-01-17 fix scale
    [SmartTemperatureTower_TPU_185-235.stl]
2021-01-17 add gcode & profile
    [SmartTemperatureTower_TPU_185-235.stl]

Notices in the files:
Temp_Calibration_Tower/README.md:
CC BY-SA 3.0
